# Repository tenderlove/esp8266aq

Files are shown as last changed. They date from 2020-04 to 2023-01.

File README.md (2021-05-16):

# My ESP8266 + Plantower AQ sensor project

This project is an ESP8266 combined with an AQ sensor and temp / humidity
sensor.  I have these set up around my house so I can monitor air quality and
temp.  The sensor publishes data to an MQTT server, then I have a listener that
connects to the MQTT server and writes all of the AQ data to an Influx
database.  I'm using Grafana to graph the data in the InfluxDB.

## Overview

Here is a photo of the completed project:

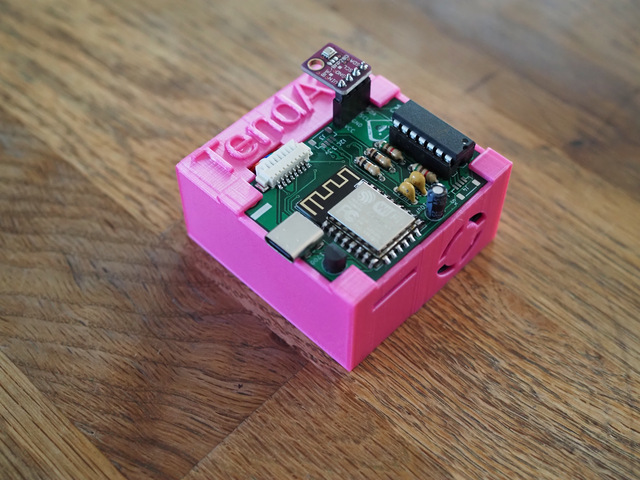
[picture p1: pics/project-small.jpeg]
Photo of Project


The sensor gets power over USB.  When you power the sensor up, it will create
an ad-hoc wifi network.  You can connect to that network then configure the
sensor with the network you want it to connect to.

## Hardware

The PCB is found in the [pcb](pcb) directory.  It's just a Kicad project.  The
[README](pcb/README.md) in that folder has more information about the hardware
side of this project (including parts, etc).

## Firmware

The firmware is found in the [firmware](firmware) directory.  The
[README](firmware/README.md) file in that folder has more information about the
firmware side of this project.

## Grafana

Here is a sample graph of the data:

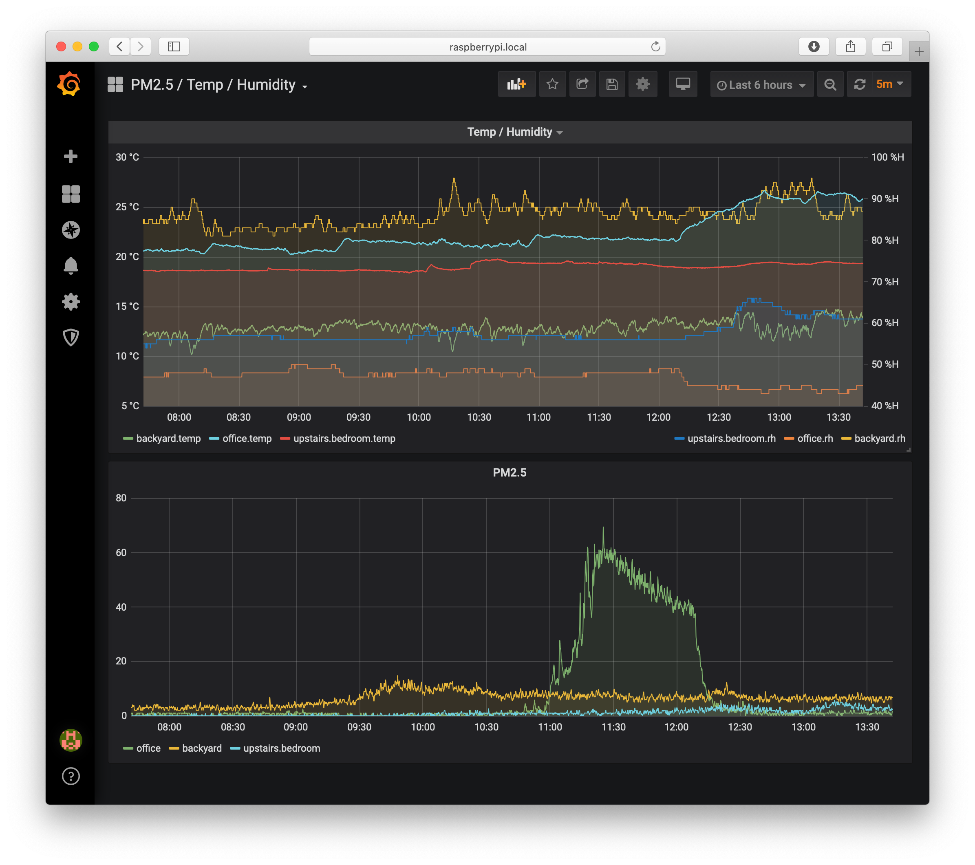
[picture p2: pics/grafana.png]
Grafana screenshot


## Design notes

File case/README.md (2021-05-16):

# My ESP8266 + Plantower AQ Sensor Project 3D printed case

This is the 3D printed case for the project.  I checked in all of the STL files
for the case, so you should be able to just print them directly.  I made two
versions of the case, one with most of the electronics exposed (because I think
it looks neat), and one where the electronics are covered but there are some
holes to let air flow.  The one with holes is more targeted toward outdoor
installations, but obviously it's not totally weatherproof.

Both cases come in two parts, `top.stl` and `bottom.stl` are the files for the
"electronics exposed" version.  `top-with-lid.stl` and `bottom-with-lid.stl`
are for the other version.

These STL files are generated using OpenSCAD and the source file is
`case.scad`.  Feel free to mess around with it and customize the case!  For
example maybe try changing "TendAir" to some other text. lol

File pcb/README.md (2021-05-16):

# My ESP8266 + Plantower AQ Sensor Project PCB

This is the PCB for the project.  I've checked in the gerber files in
`gerbers.zip`, so you can just upload that to a PCB manufacturer and get PCBs
made.  I like JLCPCB.

## Parts List

Here are the parts I used:

* [ESP-12F](https://www.digikey.com/en/products/detail/adafruit-industries-llc/2491/5761206) for WiFi [China](https://www.aliexpress.com/item/32339917567.html)
* [BME280](https://www.aliexpress.com/item/32862844557.html) for temp / humidity over I2C
* [PMS5003](https://www.aliexpress.com/item/32834164058.html) for Air Quality
* [MCP1700](https://www.digikey.com/en/products/detail/microchip-technology/MCP1700-3302E-TO/652680) 3.3v regulator
* 100nf capacitor (4.7mm ceramic disc)
* 47nf capacitor (4.7mm ceramic disc)
* 10uf capacitor (4mm radial)
* 2x 10k resistors (THT, 0207)
* 2x 5.1k resistors (THT, 0207)
* [WM7626CT-ND](https://www.digikey.com/product-detail/en/molex/0532610871/WM7626CT-ND/699113) Molex SMD connector for the AQ sensor [Europe](https://www.reichelt.nl/molex-pin-header-smd-picoblade-1x8-polig-stekker-molex-532610871-p186231.html)
* [USB4085-GF-A](https://www.digikey.com/en/products/detail/gct/USB4085-GF-A/9859733) for 5v power supply and serial communication
* [4 pin header](https://www.digikey.com/product-detail/en/sullins-connector-solutions/PPTC041LFBN-RC/S7002-ND/810144) to plug in the BME280 breakout board [Europe](https://www.reichelt.nl/female-header-2-54mm-straight-1x4-bkl-10120946-p266671.html)
* [MCP2221a](https://www.digikey.com/en/products/detail/microchip-technology/MCP2221A-I-P/6009296) for programming the ESP and serial communication
* [2x JST SH 4 pin Vertical Connector](https://www.adafruit.com/product/4328). These are optional, they're just for future extension to the board
* [IC Socket](https://www.digikey.com/en/products/detail/te-connectivity-amp-connectors/1-2199298-3/5022040) for mounting the MCP2221a

## Assembly

Some of these parts are surface mount parts and they can be somewhat tricky to solder.
I recommend using a [flux pen](https://www.amazon.com/gp/product/B074J6R1KQ/) and [fine solder wire](https://www.amazon.com/gp/product/B071G1J3W6/).

I recommend soldering in the following order:

* Resistors
* ESP
* Ceramic capacitors
* MCP1700 Voltage regulator
* IC Socket for MCP2221a
* 10uf radial capacitor
* Molex socket
* JST headers (if using)
* Header socket for BME breakout board
* USB connector

I soldered in that order because I found it easiest to keep the connectors
close to the PCB.

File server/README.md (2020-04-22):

# My ESP8266 + Plantower AQ Sensor Project Firmware

This is the firmware for the project.  I wrote an Arduino sketch.  I'd rather
have written it in C, but writing an Arduino sketch seemed like the fastest way
to get the project done, and I'd rather be finished than happy (this is a joke,
I am perfectly happy even though it isn't C).

## Prerequisites

Make sure you have Arduino IDE installed.  I like to use the command line tools,
so I made a `Makefile` that will setup most of the stuff.

You'll also need a programmer for the ESP8266.  [This
one](https://www.amazon.com/gp/product/B07KF119YB/) works well for me.

If you're on macOS, the Python path seems broken, so you might have to do this:

```
$ cd ~/Library/Arduino15/packages/esp8266/tools/python3/3.7.2-post1
$ rm python3 
$ ln -s /usr/bin/python3
```

## Command Line

If you're using the command line, just do:

1. `make setup` to install libraries
2. `make compile` to compile stuff
3. `make flash` to flash the ESP8266

If you've already assembled the PCB, this should be it.  By default the ESP8266
will create an ad-hoc network.  Connect to that network and configure the chip
with your wifi credentials.  After it connects to your network it will start
broadcasting sensor information.

See `client.rb` in the main director for a Ruby client that listens for sensor data.

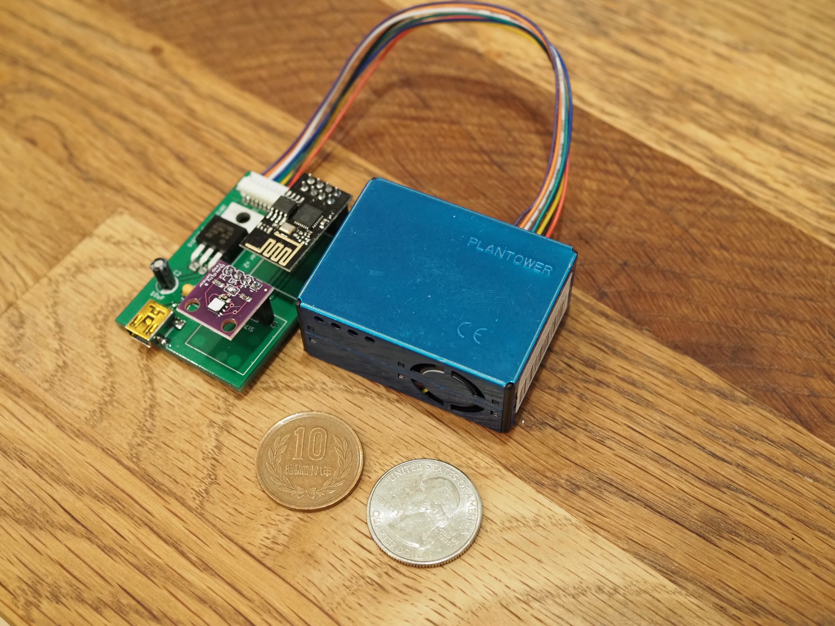
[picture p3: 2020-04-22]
pics/project.jpeg

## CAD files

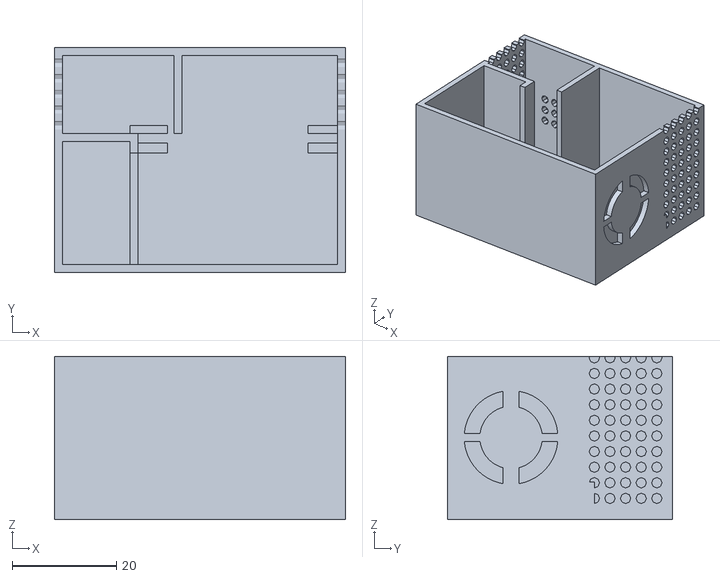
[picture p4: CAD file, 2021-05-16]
case/top-with-lid.stl
55.9 x 43.2 x 31.4

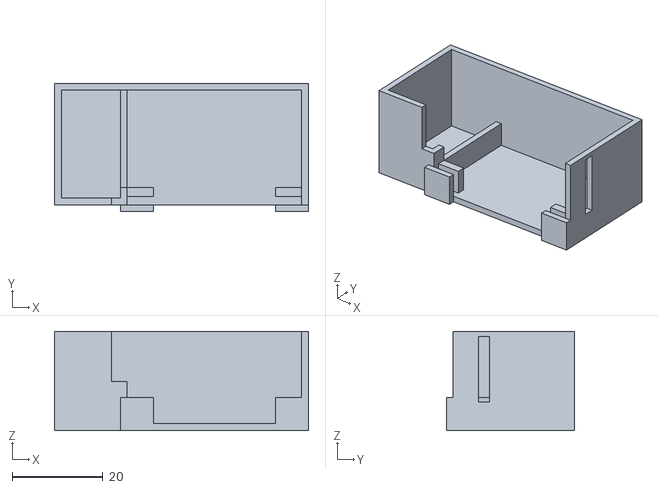
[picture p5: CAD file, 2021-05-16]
case/bottom.stl
55.9 x 28.2 x 21.8

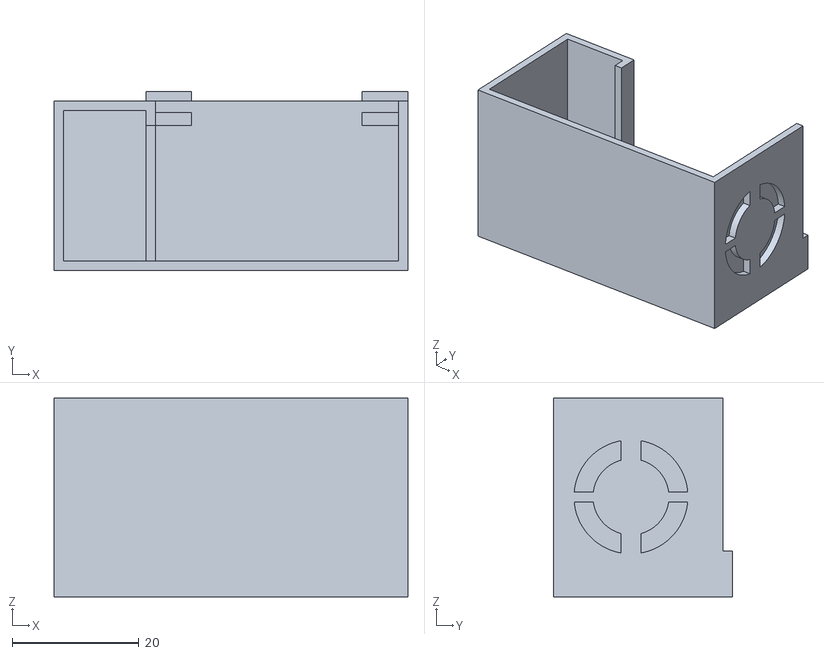
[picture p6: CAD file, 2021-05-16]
case/top.stl
55.9 x 28.2 x 31.4

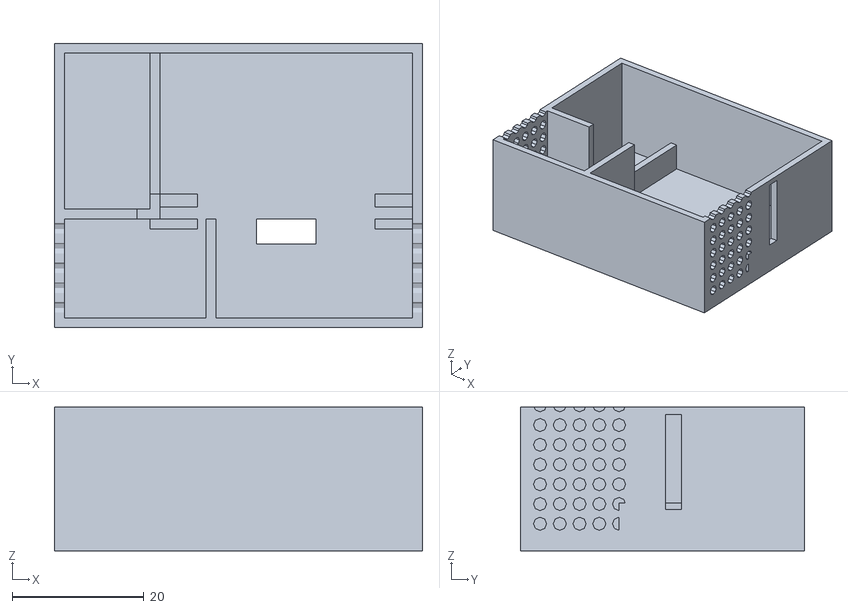
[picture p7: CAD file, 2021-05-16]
case/bottom-with-lid.stl
55.9 x 43.2 x 21.8

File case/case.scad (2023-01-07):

include <grid.scad>;

PM25_X = 38.4;
PM25_Y = 50.2;
PM25_Z = 21.4;
WALL_SIZE = 1.5;
TAB_X = 5.75;
TAB_Y = 5.75;
PCB_SPACER = 2;
PCB_THICKNESS = 1.8;
BRIM = TAB_X;
CABLE_BOX_X = 13;
CABLE_BOX_Y = PM25_Y;
CABLE_BOX_Z = PM25_Z + PCB_SPACER + PCB_THICKNESS - WALL_SIZE;
BIG_VENT_CENTER = 35.9;

// JST cable cutout
JST_DISTANCE_FROM_EDGE = 9.3;
JST_WIDTH = 11;
CABLE_SPACE = 2;

WS2 = WALL_SIZE * 2;

// Space required above the PCB
ABOVE_PCB = 15;

BME_BREAKOUT_X = 14;
BME_BREAKOUT_Y = 11;

USB_X = 9;
USB_Z = 5.6 - PCB_THICKNESS;

LID_X = CABLE_BOX_X + PM25_X + WALL_SIZE;
LID_Y = PM25_Y;
LID_Z = ABOVE_PCB;

module leftCutout() {
  translate([-WALL_SIZE, BRIM, 0])
    linear_extrude(PM25_Z)
    square(size = [WALL_SIZE, PM25_Y - (2 * BRIM)]);

  translate([-WALL_SIZE, JST_DISTANCE_FROM_EDGE, 0])
    linear_extrude(PM25_Z + PCB_THICKNESS + PCB_SPACER)
    square(size = [WALL_SIZE, JST_WIDTH]);
}

module pcbCutout() {
  translate([TAB_X, 0, PM25_Z])
    linear_extrude(PCB_SPACER + PCB_THICKNESS + WALL_SIZE)
    square(size = [PM25_X - (TAB_X * 2), PM25_Y]);

  translate([TAB_X, -WALL_SIZE, PM25_Z + PCB_SPACER + PCB_THICKNESS])
    linear_extrude(WALL_SIZE)
    square(size = [PM25_X - (TAB_X * 2), PM25_Y + WS2]);

  translate([0, TAB_Y, PM25_Z])
    linear_extrude(PCB_SPACER + PCB_THICKNESS + WALL_SIZE)
    square(size = [PM25_X, PM25_Y - (TAB_Y * 2)]);

  translate([-WALL_SIZE, TAB_Y, PM25_Z + PCB_SPACER + PCB_THICKNESS])
    linear_extrude(WALL_SIZE)
    square(size = [PM25_X + WS2, PM25_Y - (TAB_Y * 2)]);

  translate([0, 0, PM25_Z + PCB_SPACER])
    linear_extrude(PCB_THICKNESS)
    square(size = [PM25_X, PM25_Y]);
}

module fanCutOut() {
  fan_outer_radius = 9;
  fan_inner_radius = 6;
  epsilon = 1;

  translate([PM25_X - epsilon, BIG_VENT_CENTER, PM25_Z / 2])
    rotate([0, 90, 0])
    difference() {
      $fn = 90;
      linear_extrude(WALL_SIZE + epsilon)
        circle(r = fan_outer_radius);

      linear_extrude(WALL_SIZE + epsilon)
        circle(r = fan_inner_radius);

      linear_extrude(WALL_SIZE + epsilon)
        square(size = [3.1, fan_outer_radius * 2], center = true);

      linear_extrude(WALL_SIZE + epsilon)
        square(size = [fan_outer_radius * 2, 1.6], center = true);
    }
}

module portCutOut() {
  port_d = 2.45;

  translate([PM25_X, 6 - (port_d / 2), PM25_Z - (4.2 - port_d)])
    rotate([0, 90, 0])
    linear_extrude(WALL_SIZE)
    square(size = [port_d, 12.0 + port_d]);
}

module connectorCutOut() {
  jst_height = 4.9;
  jst_len = 17;
  translate([-WALL_SIZE, PM25_Y - jst_len - 5.5, (PM25_Z / 2) + jst_height / 2])
  rotate([0, 90, 0])
    color("blue")
    linear_extrude(WALL_SIZE)
    square(size = [jst_height, jst_len]);
}

module pmcutout() {
  linear_extrude(PM25_Z)
    square(size = [PM25_X, PM25_Y]);
}

module pmcase(lid = false) {
  if (lid) {
    translate([0, 0, PM25_Z + PCB_SPACER + PCB_THICKNESS + WALL_SIZE])
      Lid();
  }
  translate([CABLE_BOX_X + WALL_SIZE, 0, 0]) {
    translate([WALL_SIZE, WALL_SIZE, WALL_SIZE])
      difference() {
        translate([-WALL_SIZE, -WALL_SIZE, -WALL_SIZE])
          linear_extrude(PM25_Z + WS2 + PCB_SPACER + PCB_THICKNESS)
          square(size = [PM25_X + WS2, PM25_Y + WS2]);

        // These cutouts model the PM 2.5 sensor
        pmcutout();
        pcbCutout();
        fanCutOut();
        portCutOut();
        connectorCutOut();

        // This removes most of the side of the PM 2.5 sensor so we can
        // run a cable gutter on the side.
        leftCutout();
      }
    translate([-(CABLE_BOX_X + WALL_SIZE), 0, 0])
      cablecase();
  }
}

module cablecaseCutout() {
  linear_extrude(CABLE_BOX_Z)
    square(size = [CABLE_BOX_X, CABLE_BOX_Y]);

  translate([CABLE_BOX_X - CABLE_SPACE, JST_DISTANCE_FROM_EDGE, CABLE_BOX_Z])
    linear_extrude(WALL_SIZE)
    square(size = [CABLE_SPACE, JST_WIDTH]);
}

module cableCaseText() {
  text_depth = 1;
  text_size = 10;
  translate([(CABLE_BOX_X / 2) + (text_size / 2) - 2, CABLE_BOX_Y / 2, CABLE_BOX_Z + WALL_SIZE])
    rotate([0, 0, 90])
    linear_extrude(text_depth)
    text("TendAir", size = text_size, halign="center");
}

module cablecase() {
  translate([WALL_SIZE, WALL_SIZE, WALL_SIZE]) {
    difference() {
      translate([-WALL_SIZE, -WALL_SIZE, -WALL_SIZE])
        linear_extrude(PM25_Z + PCB_SPACER + PCB_THICKNESS + WALL_SIZE)
        square(size = [CABLE_BOX_X + WALL_SIZE, PM25_Y + WS2]);

      cablecaseCutout();
    }
    //cableCaseText();
  }
}

module BottomSlice() {
    text_height = 2;
    translate([0, JST_DISTANCE_FROM_EDGE + WALL_SIZE + JST_WIDTH, 0])
    linear_extrude(PM25_Z + PCB_SPACER + PCB_THICKNESS + WS2 + LID_Z + text_height)
      square(size = [LID_X + WS2, PM25_Y + WS2]);
}

module Bottom(case = false) {
  difference() {
    pmcase(case);
    BottomSlice();
  }
}

module Top(case = false) {
  intersection() {
    pmcase(case);
    BottomSlice();
  }
}

module BMEVentCutOut() {
  header_y = 32.7;
  header_x = CABLE_BOX_X + WALL_SIZE + 3.1;

  translate([header_x - BME_BREAKOUT_X, header_y, LID_Z])
    linear_extrude(WALL_SIZE)
    Grid(BME_BREAKOUT_X, BME_BREAKOUT_Y, inner_diameter = 2, grid_buffer = 1);
}

module USBCutOut() {
  translate([CABLE_BOX_X + WALL_SIZE + (PM25_X / 2) - (USB_X / 2), 0, 0])
  rotate([90, 0, 0])
    linear_extrude(WALL_SIZE)
    square(size = [USB_X, USB_Z]);
}

module SideVentCutOut() {
  rotate([0, -90, 0])
    linear_extrude(WALL_SIZE)
    Grid(ABOVE_PCB, PM25_Y, inner_diameter = 2, grid_buffer = 1);
}

module LidCutOut() {
  BMEVentCutOut();
  USBCutOut();

  // Right side vents
  translate([LID_X + WALL_SIZE, 0, 0])
    SideVentCutOut();

  // Left side vents
  SideVentCutOut();

  rotate([0, -90, 0])
    linear_extrude(WALL_SIZE)
    Grid(ABOVE_PCB, PM25_Y, inner_diameter = 2, grid_buffer = 1);
  rotate([0, -90, 0])
    linear_extrude(WALL_SIZE)
    Grid(ABOVE_PCB, PM25_Y, inner_diameter = 2, grid_buffer = 1);
  linear_extrude(LID_Z)
    square(size = [LID_X, PM25_Y]);
}

module LidText() {
  translate([(LID_X + WS2) / 2, ((LID_Y + WS2) / 2) + 1, LID_Z + WALL_SIZE]) {
    linear_extrude(1)
      text(text = "TendAir", valign = "center", halign = "center");
  }
}

module Lid() {
  //LidText();

  translate([WALL_SIZE, WALL_SIZE, 0])
    difference() {
      translate([-WALL_SIZE, -WALL_SIZE, 0])
        linear_extrude(LID_Z + WALL_SIZE)
        square(size = [LID_X + WS2, LID_Y + WS2]);
      LidCutOut();
    }

  // Heat isolation wall
  translate([CABLE_BOX_X + WS2 + 7, WALL_SIZE, 0])
    linear_extrude(LID_Z)
    square(size = [WALL_SIZE, PM25_Y]);
}

rendering = "full";
lid = "disabled";
should_lid = lid == "enabled" ? true : false;

if (rendering == "full") {
    pmcase(should_lid);
}

if (rendering == "top") {
  rotate([270, 0, 0])
    Top(false);
}

if (rendering == "top-with-lid") {
  rotate([270, 0, 0])
    Top(true);
}

if (rendering == "bottom") {
  rotate([90, 0, 0])
    Bottom(false);
}

if (rendering == "bottom-with-lid") {
  rotate([90, 0, 0])
    Bottom(true);
}

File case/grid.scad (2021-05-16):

function round_down(n) = n - (n % 1);

module Grid(x, y, inner_diameter = 5, grid_buffer = 2, center = false) {
  diameter = inner_diameter + grid_buffer;
  radius   = diameter / 2;
  x_n = round_down(x / diameter);
  y_n = round_down(y / diameter);
  $fn = 8;

  y_diff = y - (y_n * diameter);
  x_diff = x - (x_n * diameter);

  move = center ?
    [radius - (diameter * x_n) / 2, radius - (diameter * y_n) / 2, 0]
    :
    [radius + (x_diff / 2), radius + (y_diff / 2), 0];

  translate(move)
    for (j = [0 : (y_n - 1)]) {
      for (i = [0 : (x_n - 1)]) {
        translate([i * diameter, j * diameter, 0])
          circle(d = inner_diameter);
      }
  }
}

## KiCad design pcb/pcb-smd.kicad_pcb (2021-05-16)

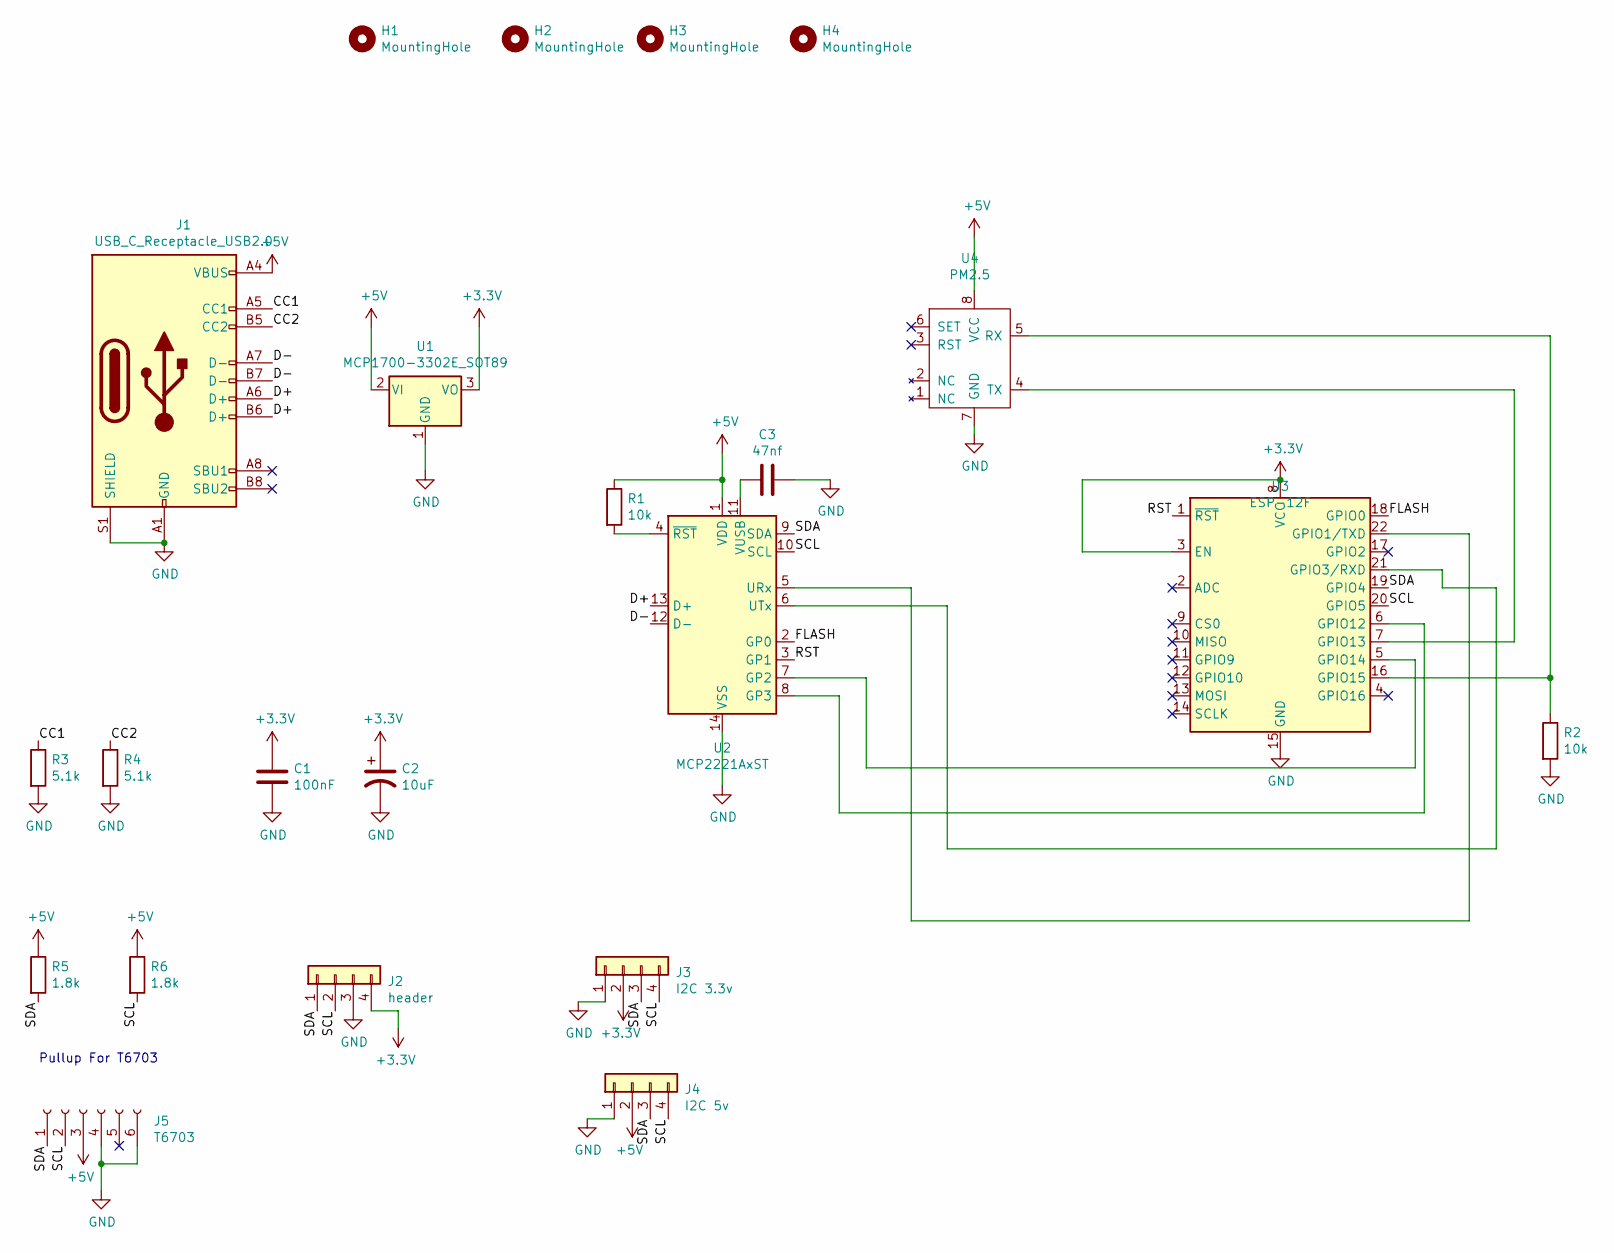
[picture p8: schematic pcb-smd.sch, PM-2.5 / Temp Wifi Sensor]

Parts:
C1: 100nF; C_1206_3216Metric_Pad1.42x1.75mm_HandSolder
C2: 10uF; C_1206_3216Metric_Pad1.42x1.75mm_HandSolder
C3: 47nf; C_1206_3216Metric_Pad1.42x1.75mm_HandSolder
H1, H2, H3, H4: MountingHole; MountingHole_2.5mm_Pad_Via
J1: USB_C_Receptacle_USB2.0; USB_C_Receptacle_GCT_USB4085
J2: header; PinSocket_1x04_P2.54mm_Vertical
J3: I2C 3.3v; JST_SH_BM04B-SRSS-TB_1x04-1MP_P1.00mm_Vertical
J4: I2C 5v; JST_SH_BM04B-SRSS-TB_1x04-1MP_P1.00mm_Vertical
J5: T6703; PinSocket_1x06_P2.54mm_Vertical
R1, R2: 10k; R_1206_3216Metric_Pad1.42x1.75mm_HandSolder
R3, R4: 5.1k; R_1206_3216Metric_Pad1.42x1.75mm_HandSolder
R5, R6: 1.8k; R_1206_3216Metric_Pad1.42x1.75mm_HandSolder
U1: MCP1700-3302E_SOT89; SOT-89-3
U2: MCP2221AxST; TSSOP-14_4.4x5mm_P0.65mm
U3: ESP-12F; ESP-12E
U4: PM2.5; Molex_PicoBlade_53261-0871_1x08-1MP_P1.25mm_Horizontal

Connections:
+3V3: C1.1, C2.1, J2.4, J3.2, U1.3 (VO), U3.3 (EN), U3.8 (VCC)
+5V: J1.A4 (VBUS), J1.A9 (VBUS), J1.B4 (VBUS), J1.B9 (VBUS), J4.2, J5.3, R1.1, R5.1, R6.1, U1.2 (VI), U2.1 (VDD), U4.8 (VCC)
/CC1: J1.A5 (CC1), R3.1
/CC2: J1.B5 (CC2), R4.1
/D+: J1.A6 (D+), J1.B6 (D+), U2.13 (D+)
/D-: J1.A7 (D-), J1.B7 (D-), U2.12 (D-)
/FLASH: U2.2 (GP0), U3.18 (GPIO0)
/RST: U2.3 (GP1), U3.1 (~RST)
/SCL: J2.2, J3.4, J4.4, J5.2, R6.2, U2.10 (SCL), U3.20 (GPIO5)
/SDA: J2.1, J3.3, J4.3, J5.1, R5.2, U2.9 (SDA), U3.19 (GPIO4)
GND: C1.2, C2.2, C3.1, J1.A1 (GND), J1.A12 (GND), J1.B1 (GND), J1.B12 (GND), J1.S1 (SHIELD), J2.3, J3.1, J4.1, J5.4, J5.6, R2.2, R3.2, R4.2, U1.1 (GND), U2.14 (VSS), U3.15 (GND), U4.7 (GND)
unnamed: C3.2, U2.11 (VUSB)
unnamed: R1.2, U2.4 (~RST)
unnamed: R2.1, U3.16 (GPIO15), U4.5 (RX)
unnamed: U2.5 (URx), U3.22 (GPIO1/TXD)
unnamed: U2.6 (UTx), U3.21 (GPIO3/RXD)
unnamed: U2.7 (GP2), U3.5 (GPIO14)
unnamed: U2.8 (GP3), U3.6 (GPIO12)
unnamed: U3.7 (GPIO13), U4.4 (TX)

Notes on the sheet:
Pullup For T6703

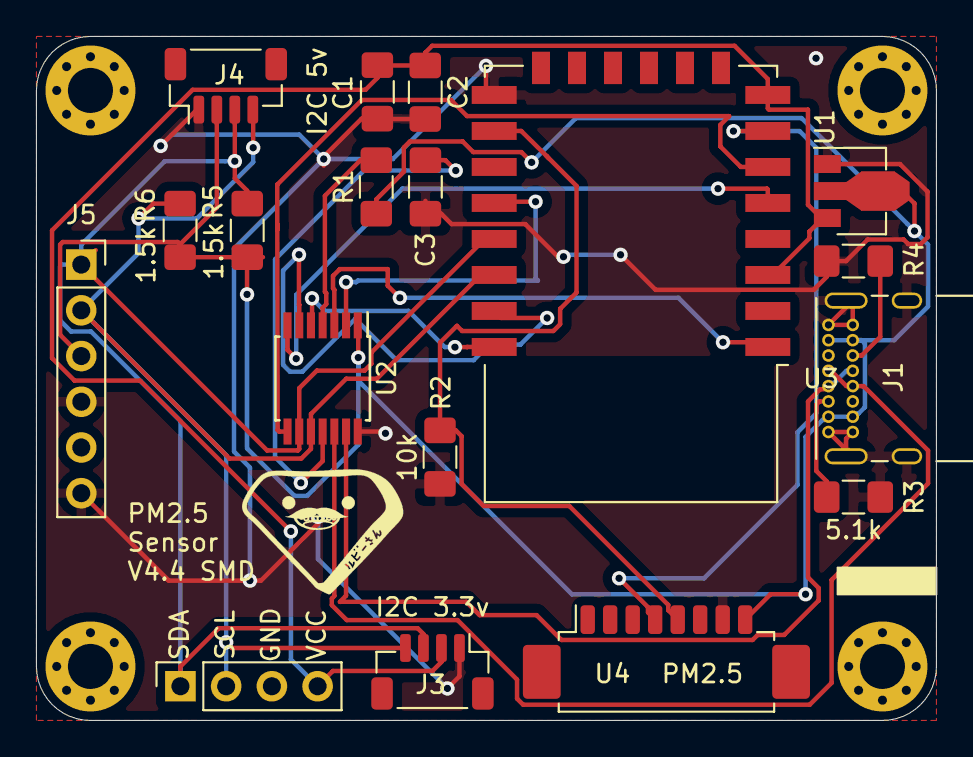
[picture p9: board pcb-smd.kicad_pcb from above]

Board: 2 copper layers, 50.0 x 38.0 mm, 22 parts (0 on the bottom side), 19 nets.

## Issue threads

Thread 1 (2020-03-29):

PCB

joostkuif, 2020-03-29:
Hi Aaron, i saw your PCB on twitter. Could you please publish/open source this too? would be great!

Joost

tenderlove, 2020-04-22:
Hi!

Thanks for filing this.  I finally got some time today and pushed the schematic and PCBs.  I've also checked in a zipfile of the gerber files so you can just upload that to whatever PCB place you like.  The gerbers are [here](https://github.com/tenderlove/esp8266aq/blob/master/pcb/gerbers.zip).

I'm working on a parts list now and I'll put that in the readme

Closed 2020-04-22.

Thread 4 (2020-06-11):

ESP connector 6 or 8?

joostkuif, 2020-06-11:
Hi Aaron,

On the parts list you have specified 6 pins for the connector. The PCB and the ESP have 8. On the picture of your resulting board I can't figure out how it is connected. Can you shine your light on this?

Thanks man!
Joost

tenderlove, 2020-06-11:
@joostkuif ah, sorry.  This is a mistake.  I meant an 8pin connector.  I'll update the documentation.

joostkuif, 2020-06-11:
Ow man, did you fell of a statue! 😜

Closed 2020-06-11.

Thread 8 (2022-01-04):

ESP-01

unlimit, 2022-01-04:
Hi Aaron,

In Jan 2021 I first time saw this project and really liked it! Then in February I bought all the necessary parts. Unfortunately I didn't have time to assemble it until now.  But now I see that ESP-01 chip was replaced with ESP-12F. I have parts for 4 devices and have doubts which way to go:
- order ESP-12F chips
- assemble devices by outdated circuit with ESP-01.

Could you please explain the advantages of ESP-12F vs ESP-01 for this project?
Thank you!

Abliamit.

tenderlove, 2022-01-04:
@unlimit The ESP-01 doesn't have as many GPIO pins exposed so I don't think there are as many features.  If you build the ESP-01 version you'll need a separate programmer module, where the ESP-12F can be programmed in-place.

Hope that helps!

Closed 2022-01-04.

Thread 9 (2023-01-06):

Fan vent cutout on case - wall being re-added

hernanat, 2023-01-06:
Hey Aaron,

I've been trying to figure this out myself for a few hours and admittedly I know pretty much nothing about CAD so it's been a struggle.

I placed an order to buy a couple of the cases with the lid from JLCPCB and they're rejecting it because the wall gets re-added / causes errors on their end for the fan vent. I opened it up in OpenSCAD and the wall does get re-added there as well, though I don't see any errors.

Here is what they told me:

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

Is there a way to get rid of the problem areas using a similar approach to what you have? When you printed this (I assume maybe you printed at home?) did you just cut the walls out yourself afterwards?

One idea I had was to try to cut out arcs, I did get an arc subtraction working but couldn't get it to the same dimensions / orienatation that you have. Do you have any pointers for a noob and once I figure it out I can open a PR (if you accept PRs)?

Thanks for this project!

hernanat, 2023-01-06:
oh! I think I figured it out! PR incoming ... not sure if it's the right thing to do or not

Closed 2023-01-08.

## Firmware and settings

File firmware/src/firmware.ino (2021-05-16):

#include <ESP8266WiFi.h>
#include <WiFiManager.h>
#include <Adafruit_Sensor.h>
#include <Adafruit_BME280.h>
#include <PubSubClient.h>
#include <LittleFS.h>
#include <ArduinoOTA.h>
#include <ArduinoJson.h>
#include <math.h>
#include <ESP8266mDNS.h>
#include <measurement.h>
#include <tp6703.h>

#ifndef NODE_NAME
#define NODE_NAME "esp8266aq"
#endif

#ifndef MQTT_SERVER
#define MQTT_SERVER ""
#endif

#ifndef MQTT_PORT
#define MQTT_PORT 1833
#endif

#ifndef MQTT_PREFIX
#define MQTT_PREFIX "esp8266aq"
#endif

#define LED_PIN 2
#define G2_PIN 14
#define G3_PIN 12

Adafruit_BME280 bme;

WiFiClient espClient;
PubSubClient client(espClient);
ESP8266WebServer server(80);

Config config;

FloatMeasurement measurement_temperature("temperature", &config);
FloatMeasurement measurement_humidity("humidity", &config);
FloatMeasurement measurement_dewpoint("dewpoint", &config);

#define NUM_MEASUREMENTS_PMS5003 12
UnsignedIntMeasurement measurements_pms5003[NUM_MEASUREMENTS_PMS5003] = {
  UnsignedIntMeasurement("pm1_0_standard", &config),
  UnsignedIntMeasurement("pm2_5_standard", &config),
  UnsignedIntMeasurement("pm10_standard", &config),
  UnsignedIntMeasurement("pm1_0_env", &config),
  UnsignedIntMeasurement("pm2_5_env", &config),
  UnsignedIntMeasurement("concentration_unit", &config),
  UnsignedIntMeasurement("particles_03um", &config),
  UnsignedIntMeasurement("particles_05um", &config),
  UnsignedIntMeasurement("particles_10um", &config),
  UnsignedIntMeasurement("particles_25um", &config),
  UnsignedIntMeasurement("particles_50um", &config),
  UnsignedIntMeasurement("particles_100um", &config)
};

UnsignedIntMeasurement measurement_co2("co2", &config);

struct PMS5003 {
  byte input_string[32];
  int input_idx;

  PMS5003() : input_idx(0) {}

  void process_byte(byte in) {
    if(input_idx == 32) {
      input_idx = 0;
    }

    input_string[input_idx++] = in;
    if (input_idx == 1 && input_string[0] != 0x42) {
      input_idx = 0;
    } else if (input_idx == 2 && input_string[1] != 0x4d) {
      input_idx = 0;
    }
  }

  void reset_input() {
    input_idx = 0;
  }

  unsigned int get_value(int idx) {
    byte high = input_string[4 + idx * 2];
    byte low  = input_string[4 + idx * 2 + 1];
    return (high << 8) | low;
  }

  /* Are we a full, valid packet */
  bool is_valid_packet() {
    if (input_idx != 32)
      return false;

    /* TODO: check crc */

    return true;
  }
};

PMS5003 pms5003;

typedef StaticJsonDocument<512> ConfigJsonDocument;

static void loadConfigurationFromDoc(Config &config, ConfigJsonDocument &doc) {
  if (doc["mqtt_server"])
    config.mqtt_server = doc["mqtt_server"].as<String>();

  if (doc["mqtt_port"])
    config.mqtt_port = doc["mqtt_port"].as<String>().toInt();

  if (doc["mqtt_prefix"])
    config.mqtt_prefix = doc["mqtt_prefix"].as<String>();
}

void loadConfiguration(Config &config) {
  /* Load defaults */
  config.name = NODE_NAME;
  config.mqtt_server = MQTT_SERVER;
  config.mqtt_port = MQTT_PORT;
  config.mqtt_prefix = MQTT_PREFIX;

  if (LittleFS.exists("config.json")) {
    File file = LittleFS.open("config.json", "r");

    ConfigJsonDocument doc;
    DeserializationError error = deserializeJson(doc, file);

    if (!error) {
      loadConfigurationFromDoc(config, doc);
      return;
    }

    file.close();
  }

}

void configModeCallback(WiFiManager *myWiFiManager) {
  Serial.println("Entered config mode");
  Serial.println(WiFi.softAPIP());
  Serial.println(myWiFiManager->getConfigPortalSSID());
}

String getContentType(String filename) {
  if (filename.endsWith(".html")) return "text/html";
  else if (filename.endsWith(".css")) return "text/css";
  else if (filename.endsWith(".js")) return "application/javascript";
  else if (filename.endsWith(".json")) return "application/json";
  else if (filename.endsWith(".ico")) return "image/x-icon";
  return "text/plain";
}

bool handleFileRead(String path) {
  if (path.endsWith("/"))
    path += "index.html";

  String contentType = getContentType(path);
  if (LittleFS.exists(path)) {
    File file = LittleFS.open(path, "r");
    server.streamFile(file, contentType);
    file.close();
    return true;
  }

  return false;
}

void webHandleStatus() {
  String json;
  json.reserve(1024);
  json += "{\"measurements\": [";

  measurement_temperature.publish(json);
  measurement_humidity.publish(json);
  for(int i = 0; i < NUM_MEASUREMENTS_PMS5003; i++) {
    measurements_pms5003[i].publish(json);
  }
  json.remove(json.lastIndexOf(",")); // remove trailing comma

  json += "], \"current_time\": ";
  json += millis();
  json += ", \"mqtt\": {\"connected\": ";
  json += client.connected() ? "true" : "false";
  json += ", \"server\": \"";
  json += config.mqtt_server;
  json += "\", \"port\": ";
  json += config.mqtt_port;
  json += "}, \"esp8266\": {\"heap_free\":";
  json += ESP.getFreeHeap();
  json += ", \"heap_fragmentation\": ";
  json += ESP.getHeapFragmentation();
  json += ", \"heap_max_free_block_size\": ";
  json += ESP.getMaxFreeBlockSize();
  json += "}}";

  server.sendHeader("Access-Control-Allow-Origin", "*");
  server.send(200, "application/json", json);
}

void webHandleUpdateConfig() {
  String body = server.arg("plain");

  File file = LittleFS.open("config.json", "w");
  file.print(body);
  file.close();

  server.send(200, "text/json", "{\"success\":true}" );

  ESP.restart();
}

void webHandleReadConfig() {
  String json;
  json.reserve(1024);

  json += "{\"name\": \"";
  json += config.name;
  json += "\", \"mqtt_server\": \"";
  json += config.mqtt_server;
  json += "\", \"mqtt_port\": \"";
  json += config.mqtt_port;
  json += "\", \"mqtt_prefix\": \"";
  json += config.mqtt_prefix;
  json += "\"}";

  server.sendHeader("Access-Control-Allow-Origin", "*");
  server.send(200, "application/json", json);
}

void setup() {
  WiFiManager wifiManager;

  pinMode(G2_PIN, INPUT);
  pinMode(G3_PIN, INPUT);
  pinMode(LED_PIN, OUTPUT);
  digitalWrite(2, HIGH);

  Serial.begin(9600);
  wifiManager.setAPCallback(configModeCallback);
  wifiManager.autoConnect();

  randomSeed(micros());

  while (WiFi.status() != WL_CONNECTED) {
    delay(500);
  }

  if (!bme.begin(0x76)) {
    Serial.println("Couldn't find BME280 sensor");
    delay(50);
  }
  LittleFS.begin();
  loadConfiguration(config);
  Serial.print("Node name: ");
  Serial.println(config.name);
  Serial.print("MQTT Server: ");
  Serial.println(config.mqtt_server);
  Serial.print("MQTT Port: ");
  Serial.println(config.mqtt_port);
  Serial.print("MQTT Prefix: ");
  Serial.println(config.mqtt_prefix);
  Serial.print("GPIO: ");
  Serial.print(digitalRead(G2_PIN));
  Serial.println(digitalRead(G3_PIN));

  MDNS.begin(config.name);

  ArduinoOTA.begin();

  Serial.flush();
  Serial.swap(); // Switch to sensor

  server.on("/config.json", HTTP_POST, webHandleUpdateConfig);
  server.on("/config.json", HTTP_GET, webHandleReadConfig);
  server.on("/status.json", HTTP_GET, webHandleStatus);
  server.onNotFound([]() {
    if (!handleFileRead(server.uri()))
      server.send(404, "text/plain", "404: Not Found");
  });

  server.begin();
}

void mqtt_reconnect() {
  static unsigned long last_attempt = 0;
  if (millis() - last_attempt < 5000) {
    return;
  }

  last_attempt = millis();
  Serial.swap();
  if (config.mqtt_server.length() && config.mqtt_port) {
    if (WiFi.hostByName(config.mqtt_server.c_str(), config.address)) {
      client.setServer(config.address, config.mqtt_port);
      String clientId = config.name;
      if(client.connect(clientId.c_str())) {
        Serial.println("Connected\n");
      } else {
        Serial.println(clientId);
        Serial.println(config.address);
        Serial.print("failed, rc=");
        Serial.println(client.state());
      }
    } else {
      Serial.print("Couldn't find address: ");
      Serial.println(config.mqtt_server);
    }

  }
  Serial.flush();
  Serial.swap();
}

void readI2CSensors(void) {
  static unsigned long last_time_measurement = 0;

  if(millis() - last_time_measurement > 1000){
    last_time_measurement = millis();

    float temp = bme.readTemperature();
    float rh = bme.readHumidity();

    // https://bmcnoldy.rsmas.miami.edu/humidity_conversions.pdf
    float x = (17.625 * temp) / (243.04 + temp);
    float l = log(rh / 100.0);
    float dewpoint = 243.04 * (l + x) / (17.625 - l - x);

    measurement_temperature.record(temp);
    measurement_humidity.record(rh);
    measurement_dewpoint.record(dewpoint);

    measurement_temperature.publish(&client);
    measurement_humidity.publish(&client);
    measurement_dewpoint.publish(&client);

    int co2 = readCO2();
    if (co2 > 0) {
      measurement_co2.record(co2);
      measurement_co2.publish(&client);
    }

    // Publish to the serial client if G2 pin is HIGH
    if (digitalRead(G2_PIN) == HIGH) {
      Serial.flush();
      Serial.swap();
      measurement_temperature.publish(&Serial);
      measurement_humidity.publish(&Serial);
      measurement_dewpoint.publish(&Serial);
      if (co2 > 0) {
        measurement_co2.publish(&Serial);
      }
      Serial.flush();
      Serial.swap();
    }
  }
}

void loop() {
  if (client.connected()) {
    client.loop();
  } else {
    mqtt_reconnect();
  }

  if (client.connected()) {
    digitalWrite(LED_PIN, LOW); // LOW == ON
  } else {
    digitalWrite(LED_PIN, HIGH);
  }

  server.handleClient();
  ArduinoOTA.handle();

  /* If there is more than one packet in the buffer we only want the most recent */
  while (Serial.available() > 32) {
    Serial.read();
    pms5003.reset_input();
  }

  while (Serial.available()) {
    pms5003.process_byte(Serial.read());

    if (pms5003.is_valid_packet()) {
      if (!client.connected()) {
        Serial.swap();
        Serial.println("MQTT client is not connected");
        Serial.flush();
        Serial.swap();
      }

      for(int i = 0; i < NUM_MEASUREMENTS_PMS5003; i++) {
        unsigned int value = pms5003.get_value(i);

        measurements_pms5003[i].record(value);
        measurements_pms5003[i].publish(&client);
      }

      // Publish to the serial client if G2 pin is HIGH
      if (digitalRead(G2_PIN) == HIGH) {
        Serial.flush();
        Serial.swap();
        for(int i = 0; i < NUM_MEASUREMENTS_PMS5003; i++) {
          measurements_pms5003[i].publish(&Serial);
        }
        Serial.flush();
        Serial.swap();
      }
    }
  }

  readI2CSensors();
}

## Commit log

2020-04-22 adding temp / humidity sensor
2020-04-22 adding pcb
    [pm_25.kicad_pcb, pm_25.sch]
2020-04-22 adding esp8266 footprint submodule
2020-04-22 fix the sample program
2020-04-22 make the PCB the same size as the plantower sensor
    [pm_25.kicad_pcb, pm_25.sch]
2020-04-22 Fix directories, add a clean task
    [firmware.ino]
2020-05-10 Combine temperature and humidity reading
    This also sends a more precise humidity reading
2020-05-17 Reset index if inputString[0] doesn't match
    I believe this fixes an issue where the communication with the AQ sensor
    gets out of sync and we stay off by one skipping over the magic start
    sequence.
    [firmware.ino]
2020-06-11 s/6 pin/8 pin/
    This should have been an 8 pin connector. Fixes #4
2020-10-24 Remove arduino
2021-02-04 somewhat case
    [case2.scad]
2021-02-05 it seems not bad now
    [case2.scad]
2021-02-05 updating pcb
    [pm_25.kicad_pcb, pm_25.sch]
2021-02-05 fixing file name
    [case.scad]
2021-02-05 adding makefile and stls
    [bottom.stl, top.stl]
2021-02-05 updating makefile and scad
    [case.scad, top.stl]
2021-02-05 updating case, removing unused stuff
    [case.scad, top.stl]
2021-02-06 updating model again
    [bottom.stl, case.scad, top.stl]
2021-02-09 adding lid to container with some test text
    [bottom.stl, case.scad, grid.scad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]
2021-02-09 add some text to the cable case lol
    [case.scad]
2021-02-12 Enable ArduinoOTA
2021-02-12 fix bugs introduced by my bad merge
    [firmware.ino]
2021-02-14 fix serial echo of temp / rh
    [firmware.ino]
2021-02-14 Cache calculated topic name, avoid varg
    push publish to measurement object
    [firmware.ino]
2021-02-15 Add client script for sensors
2021-02-17 Turn on the LED when we've connected to the MQTT server
2021-02-17 I guess Kicad wanted to change some stuff
    [pm_25.sch]
2021-02-17 make the text stick out
    [case.scad]
2021-02-17 add new STL files
    [bottom-with-lid.stl, bottom.stl, case.scad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]
2021-02-17 renaming directory
    [bottom-with-lid.stl, bottom.stl, case.scad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]
2021-02-17 Add assembly documentation
2021-02-27 Fix name
    [case.scad]
2021-02-28 making it look better
    [pm_25.kicad_pcb, pm_25.sch]
2021-03-04 Fix floating point recording
    [firmware.ino]
2021-03-11 update pcb with pulldown resistors for USB-C
    [pm_25.kicad_pcb, pm_25.sch]
2021-03-14 oops. Fix gp3 pin
2021-03-23 updating gerbers
2021-03-23 updating case
    [bottom-with-lid.stl, bottom.stl, case.scad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]
2021-04-18 add smd gerbers and pcb
    [pcb-smd.kicad_pcb, pcb-smd.sch]
2021-04-18 add readme for case
2021-05-16 Update license to include PCB artwork
2023-01-06 ensure fan vent is properly subtracted
    Previously, the fan vent subtraction was leaving a thin layer on the
    wall, but we want a hole.
    I _think_ it might have something to do with [this](https://en.wikibooks.org/wiki/OpenSCAD_User_Manual/The_OpenSCAD_Language#difference) section of the docs, namely:
    > It is mandatory that surfaces that are to be removed by a difference
    > operation have an overlap, and that the negative piece being removed
    > extends fully outside of the volume it is removing that surface from.
    Previously, what I _think_ was happening (I know next to nothing about
    OpenSCAD / CAD in general so I might be wrong) was that the surface
    being removed did not extend fully out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
    [case.scad]

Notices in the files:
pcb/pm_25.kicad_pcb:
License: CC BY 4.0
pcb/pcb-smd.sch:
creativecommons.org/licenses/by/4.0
